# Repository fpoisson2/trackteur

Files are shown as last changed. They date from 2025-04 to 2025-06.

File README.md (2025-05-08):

# Suivi de véhicule DIY pour Traccar

Ce dépôt propose une solution complète de suivi de véhicule en temps réel, basée sur Arduino, GPS et GSM/GPRS, et compatible avec la plateforme Traccar (https://www.traccar.org/).

## Structure du dépôt
- `code/` : code source Arduino
- `pcb/` : fichiers de conception PCB sous KiCad
- `logo.png` : logo du projet

## Description
Le système récupère les données GPS, les enregistre sur une carte SD (formaté avec Petit FatFs) et les transmet via un module LTE ou GPRS à un serveur Traccar, permettant de suivre la position du véhicule sur une interface web.

Le projet est compatible avec les modules suivants :
 - SIM7000G (LTE-M / NB-IoT)
 - SIM7070G (LTE-M / NB-IoT)
 - A7670E (LTE Cat-1)

Le code détecte automatiquement le module connecté et ajuste les commandes AT, la gestion du GNSS et les protocoles réseau.

## Matériel requis
- Arduino (Pro Mini, Uno, etc.)
- Module LTE/GPRS : SIM7000G, SIM7070G ou A7670E
- Carte SD et lecteur de carte SD
- Antennes GPS et GSM
- Câbles de connexion
- Alimentation (5 V ou batterie LiPo)

## Installation et utilisation
1. Cloner le dépôt :
   ```
   git clone https://github.com/votre-utilisateur/projet-suivi-vehicule.git
   ```
2. Ouvrir le dossier `code/` dans l'IDE Arduino.
3. Configurer les paramètres dans `code.ino` (serveur Traccar, APN, broches, etc.).
4. Connecter le matériel :
   - Module LTE/GSM vers broches RX/TX (utilise SoftwareSerial)
   - Lecteur SD sur SPI (pins 10–13)
5. Insérer la carte SIM et la carte SD.
6. Alimenter le montage.
7. Lancer votre serveur Traccar et vérifier la réception des positions.

## Personnalisation
- Adapter les constantes (APN, intervalles d'envoi) dans `common.h`.
- Modifier les broches et configurations dans `code.ino` selon votre matériel.

## Contribution
Les contributions sont les bienvenues !  
Forkez le dépôt, créez une branche et ouvrez une pull request.

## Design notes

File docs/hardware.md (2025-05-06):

# Matériel

## Schéma électrique

Insérez ici le schéma du circuit et le PCB exporté.

## Liste des composants (BOM)

| Quantité | Référence | Description |
|---|---|---|
| 1 | Arduino | Nano ou Pro Mini |

(Compléter avec toutes les pièces.)

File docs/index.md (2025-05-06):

# Documentation du Trackteur Arduino

Bienvenue dans la documentation du projet Trackteur Arduino.

Ce site couvre :

- Présentation du projet
- Matériel
- Guide d'assemblage
- Logiciel (configuration & déploiement)
- Dépannage / FAQ
- Contribution

Utilisez le menu à gauche pour naviguer.

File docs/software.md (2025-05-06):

# Logiciel

## Prérequis

- Arduino IDE (>=1.8)
- Bibliothèques : TinyGPS++, SdFat, GSMStream (ou équivalent)

## Installation

```bash
arduino-cli compile --fqbn arduino:avr:nano code/code.ino
arduino-cli upload -p /dev/ttyUSB0 --fqbn arduino:avr:nano code/code.ino
```

## Configuration

- APN opérateur
- URL Traccar
- Config pins dans common.h

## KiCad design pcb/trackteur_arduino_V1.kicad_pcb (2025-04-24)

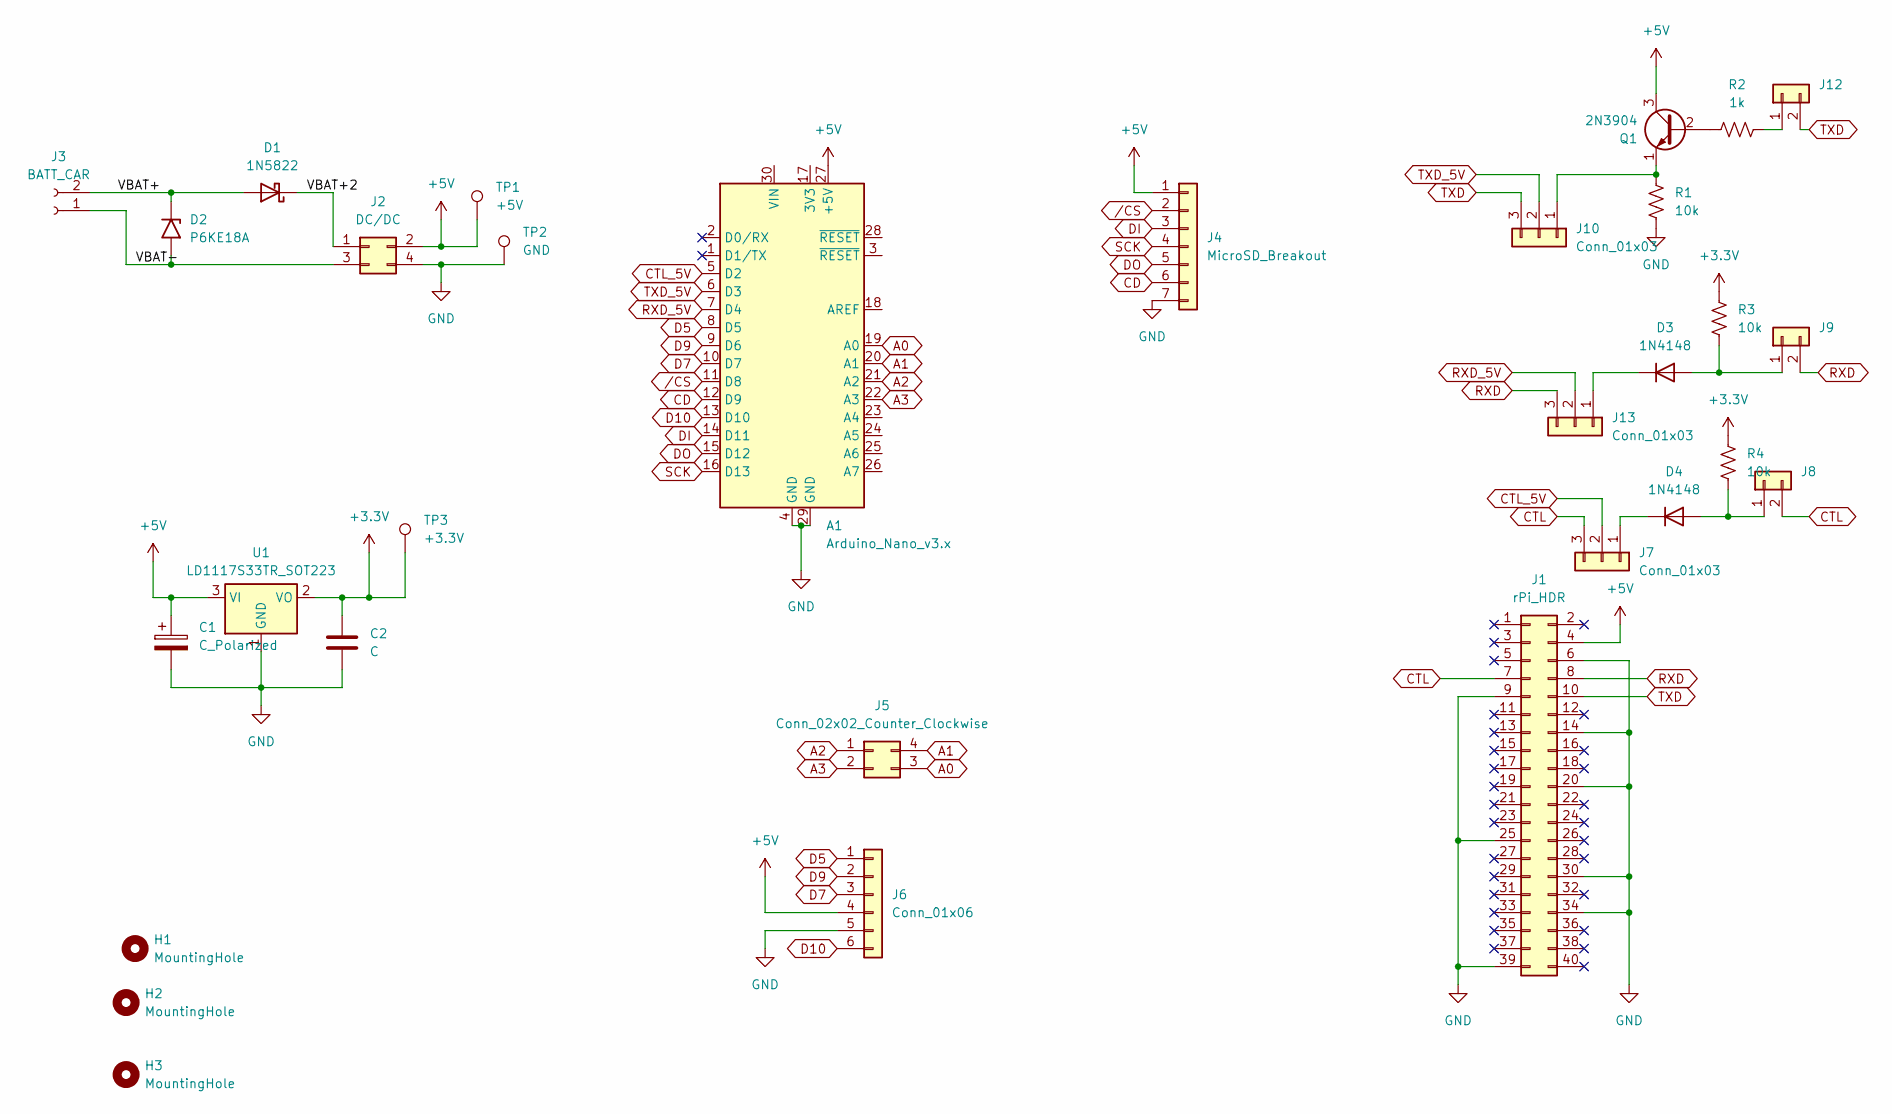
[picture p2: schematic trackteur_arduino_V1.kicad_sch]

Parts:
A1: Arduino_Nano_v3.x; Arduino_Nano
C1: C_Polarized; CP_Radial_D5.0mm_P2.50mm
C2: C; C_Disc_D5.0mm_W2.5mm_P5.00mm
D1: 1N5822; D_DO-201AD_P15.24mm_Horizontal
D2: P6KE18A; D_DO-15_P12.70mm_Horizontal
D3, D4: 1N4148; D_DO-35_SOD27_P7.62mm_Horizontal
H1, H2, H3: MountingHole; MountingHole_2.7mm_M2.5
J1: rPi_HDR; PinHeader_2x20_P2.54mm_Vertical
J2: DC/DC; LM2596_DC_DC_MODULE
J3: BATT_CAR; TE_282837-2
J4: MicroSD_Breakout; PinHeader_1x07_P2.54mm_Vertical
J5: Conn_02x02_Counter_Clockwise; PinHeader_2x02_P2.54mm_Vertical
J6: Conn_01x06; PinHeader_1x06_P2.54mm_Vertical
J7, J10, J13: Conn_01x03; PinHeader_1x03_P2.54mm_Vertical
J8, J9, J12: Conn_01x02; PinHeader_1x02_P2.54mm_Vertical
Q1: 2N3904; TO-92_Inline
R1, R3, R4: 10k; R_Axial_DIN0207_L6.3mm_D2.5mm_P10.16mm_Horizontal
R2: 1k; R_Axial_DIN0207_L6.3mm_D2.5mm_P10.16mm_Horizontal
TP1: +5V; PinHeader_1x01_P2.54mm_Vertical
TP2: GND; PinHeader_1x01_P2.54mm_Vertical
TP3: +3.3V; PinHeader_1x01_P2.54mm_Vertical
U1: LD1117S33TR_SOT223; TO-220-3_Vertical

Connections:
+3.3V: C2.1, R3.2, R4.2, TP3.1, U1.2 (VO)
+5V: A1.27 (+5V), C1.1, J1.4, J2.2, J4.1, J6.4, Q1.3 (C), TP1.1, U1.3 (VI)
/VBAT+: D1.2 (A), D2.1 (A1), J3.2
/VBAT+2: D1.1 (K), J2.1
/VBAT-: D2.2 (A2), J2.3, J3.1
A0: A1.19 (A0), J5.3
A1: A1.20 (A1), J5.4
A2: A1.21 (A2), J5.1
A3: A1.22 (A3), J5.2
CD: A1.12 (D9), J4.6
CTL: J1.7, J7.3, J8.2
CTL_5V: A1.5 (D2), J7.2
D5: A1.8 (D5), J6.1
D7: A1.10 (D7), J6.3
D9: A1.9 (D6), J6.2
D10: A1.13 (D10), J6.6
DI: A1.14 (D11), J4.3
DO: A1.15 (D12), J4.5
GND: A1.4 (GND), A1.29 (GND), C1.2, C2.2, J1.6, J1.9, J1.14, J1.20, J1.25, J1.30, J1.34, J1.39, J2.4, J4.7, J6.5, R1.1, TP2.1, U1.1 (GND)
unnamed: D3.2 (A), J9.1, R3.1
unnamed: D3.1 (K), J13.1
unnamed: D4.2 (A), J8.1, R4.1
unnamed: D4.1 (K), J7.1
unnamed: J10.1, Q1.1 (E), R1.2
unnamed: J12.1, R2.2
unnamed: Q1.2 (B), R2.1
RXD: J1.8, J9.2, J13.3
RXD_5V: A1.7 (D4), J13.2
SCK: A1.16 (D13), J4.4
TXD: J1.10, J10.3, J12.2
TXD_5V: A1.6 (D3), J10.2
/CS: A1.11 (D8), J4.2

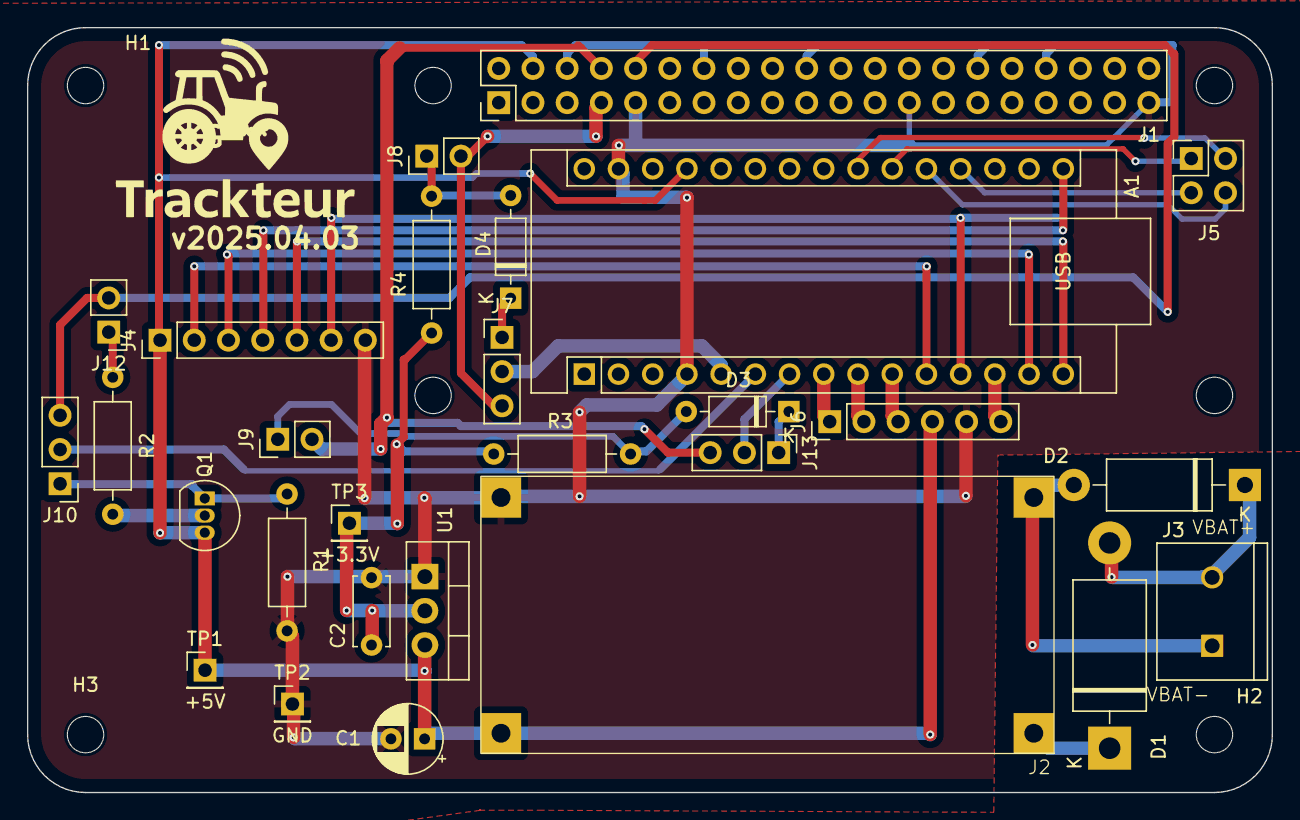
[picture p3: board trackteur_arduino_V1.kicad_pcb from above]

Board: 2 copper layers, 92.4 x 56.8 mm, 35 parts (0 on the bottom side), 32 nets.

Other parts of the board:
H2#2, H4, H5: MountingHole_2.7mm_M2.5
H3#2: MountingHole; MountingHole_2.7mm_M2.5

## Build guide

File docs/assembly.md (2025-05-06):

# Assemblage pas-à-pas

## Pré-requis

- Fer à souder
- Multimètre
- Tournevis

## Étapes

1. Soudure des résistances et condensateurs
2. Insertion des supports SIM et µSD
3. Montage du module GSM/GPS
4. Vérification des connexions
5. Montage dans le boîtier

Ajoutez des photos à chaque étape.

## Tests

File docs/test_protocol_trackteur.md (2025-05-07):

# Protocole de Validation Exhaustif — Projet **Trackteur**

**Version :** 1.0   **Révision du firmware testée :** `$(git rev-parse --short HEAD)`

*NB : ce protocole s’appuie sur l’implémentation exacte observée dans le dépôt (fichiers `code/*`). Les libellés, messages **Serial** et noms de fonctions cités proviennent du code source et permettent une traçabilité directe entre les tests et l’implémentation.*

---

## Table des matières
1. Objectifs et portée
2. Prérequis
   2.1 Matériel 2.2 Logiciel 2.3 Préparation du banc
3. Convention de nommage & journalisation
4. Plan de test détaillé (pas-à-pas)
   * 4.1 Initialisation « cold-boot »
   * 4.2 Pile réseau LTE & détection SIM
   * 4.3 GNSS : acquisition & parsing (`getGpsData`)
   * 4.4 SD : moteur Petit FatFs (`sdlog.cpp`)
   * 4.5 Flux Traccar (`sendGpsToTraccar`)
   * 4.6 Watch-dog & résilience (`serviceNetwork`, `resetGsmModule`)
   * 4.7 Tests de bordure & corruption (fichiers, buffers, wrap-around)
5. Critères de succès/échec
6. Collecte des preuves & archivage
7. Annexes

---

## 1. Objectifs et portée

Valider que **Trackteur** – matériel, firmware et logique back-end – fonctionne dans toutes les conditions prévues par le code (fichiers `code/*.cpp`).

• Fiabilité du boot, absence de sur-consommation (< 200 mA @ 5 V lors du pic d’initialisation observé dans `setup()`).  
• Bon déroulement de la séquence **`serviceNetwork()`** : `initialCommunication()` ► `step1…4` ► état `NetState::ONLINE`.  
• Performance des fonctions critiques : `getGpsData`, `openDataStack`, `tcpSend`, `logRealPositionToSd`, etc.  
• Robustesse face aux fautes : perte réseau, corruption secteur, overflow de buffers (**`RESPONSE_BUFFER_SIZE` = 128 octets**), redémarrage forcé (watch-dog).  
• Conformité du format de trame HTTP GET attendu par Traccar.

## 2. Prérequis

### 2.1 Matériel

| Réf | Qté | Détails |
|---|---|---|
| Carte Trackteur assemblée | 2 | Une avec **SIM7000G**, une avec **A7670E** (détection via `ATI`) |
| Alim de labo 5 V / 2 A | 1 | Lim courant ajustable |
| Batterie Li-ion 18650 2400 mAh | 1 | Test coupure secteur |
| Câble USB-TTL 115 200 bps mini | 1 | Console debug (pins RX0/TX0) |
| Antennes LTE & GNSS | 1+1 | Connecteurs U.FL ≈50 Ω |
| SIM M2M **data** | 1 | APN : *onomondo* (cf. `const char* APN`) |
| micro-SD 4 Go class 10 | 1 | Format FAT32, sector size 512 o |
| PC Windows/Linux | 1 | Ports USB, Python ≥ 3.8 |
| Multimètre + oscillo ≥ 50 MHz | - | Vér. VCC, bruit, toggles GPIO |
| Cage Faraday (boite métal) | - | Simuler perte réseau |

### 2.2 Logiciel

• Toolchain Arduino / PlatformIO (AVR-gcc 5+).  
• Terminal série : `minicom`, `PuTTY` ou équivalent **avec log cru**.  
• Python 3 + dépendances (`pyserial`, `pandas`) : scripts `tools/trackteur_harness.py` (fourni).  
• Serveur **Traccar** (v5+) local : accès au log `tracker-server.log`.  
• Optionnel : simulateur NMEA (plages de tests GNSS en intérieur).

### 2.3 Préparation du banc

1. Flasher la révision *release-candidate* (`git checkout <tag>`).  
2. Sauvegarder le SHA-1 dans la feuille de résultat.  
3. Vérifier soudures, polarités et **continuité D2** (GPIO `powerPin`).  
4. Insérer la micro-SD puis exécuter `initializeSD()` via un sketch simple : assure un montage OK avant campagne.  
5. Insérer la carte SIM, antennes GNSS & LTE (vérifier pas d’inversion).  
6. Relier la console série (115 200 bps). Activer *capture RAW*.

---

## 3. Convention de nommage & journalisation

• Un ID unique `T-<Domaine>-NNN` par cas (ex :`T-GSM-012`).  
• Tous les logs **Serial** doivent être conservés : `/logs/YYYY-MM-DD/<ID>.log`.  
• Scripts Python : chaque test écrit un CSV `/results/YYYY-MM-DD/<ID>.csv` avec **timestamp ISO8601**, `result`, `duration_ms`, et commentaires.  
• Photos/Vidéos : nom `IMG_<ID>_stepX.jpg`.

---

## 4. Plan de test détaillé

### Lecture des colonnes

* Pré-cond. = état et configuration à respecter avant déroulé.  
* Étapes = séquence manuelle/automatisée.  
* Attendu = critère de succès issu **des messages ou valeurs retournées**.  
* Timeout/itération = valeur max avant échec.

### 4.1 Cold-boot & Initialisation

| ID | Objectif | Pré-cond. | Étapes | Attendu / Timeout |
|----|---|---|---|---|
| T-BOOT-001 | Absence de sur-conso | Alim labo 5 V ; I_lim = 500 mA | Alimenter. | I_crête < 200 mA (lecture multimètre ‹ 5 s). |
| T-BOOT-002 | Bannière USB visible | UART ouvert 115 200 bps | Presse **RESET** MCU | Log « `--- Arduino Initialized ---` » < 1 s. |
| T-BOOT-003 | Setup terminé | | Observer console | « `=== SETUP TERMINÉ ===` » < 10 s. |
| T-BOOT-004 | Watchdog actif | Modifier `initializeWatchdog()` pour activer `wdt_enable(WDTO_8S)` et re-flasher | Laisser tourner 30 min | Aucun reset impromptu. |

### 4.2 Pile réseau & SIM

| ID | Objectif | Pré-cond. | Étapes | Attendu |
|----|---|---|---|---|
| T-GSM-010 | Détection modem | Démarrage normal | Vérifier log `>> Modem detected: ...` | Modèle correct (`SIM7000G` ou `A7670E`). |
| T-GSM-020 | `initialCommunication()` | | Surveiller log | Suite d’`OK` pour `ATE0`, `AT+CMEE=2` etc. |
| T-GSM-030 | APN configuré | | Chercher « `AT+CGDCONT=1,"IP","onomondo"` » | APN = constante `APN`. |
| T-GSM-040 | SIM Ready | | Confirmer `SIM Ready.` | Reçu < 15 s. |
| T-GSM-050 | Enregistré réseau | | `Registered.` dans log | ‹ 60 s sinon **E**. |
| T-GSM-060 | `openDataStack()` | | LOG « `✔ TCP connection successful` » ou `NETOPEN OK` | 3 tentatives max. |
| T-GSM-070 | Reconnexion OFFLINE→ONLINE | Forcer réseau OFF (boite Faraday 2 min) | Observer bascule `NetState::OFFLINE` puis reconnection | Reprise < RECONNECT_PERIOD (60 s). |

### 4.3 GNSS (`gps.cpp`)

| ID | Objectif | Étapes | Succès |
|----|---|---|---|
| T-GPS-100 | `getGpsData` valid – SIM7000 | Champ libre ciel dégagé | Temps fix (`run=1, fix=1`) < 45 s. |
| T-GPS-110 | `getGpsData` valid – A7670 | `AT+CGPSINFO` | Champs non-vides, TS parsé. |
| T-GPS-120 | Format timestamp | Inspecter buffer `gpsTimestampTraccar` | Format `YYYY-MM-DD%20hh:mm:ss`. |
| T-GPS-130 | Précision position | Comparer à coord. réf. (DGPS) | Δ < ±15 m. |
| T-GPS-140 | Robustesse buffer | Envoyer réponse +CGNSINF de 200 car. (script) | Pas d’overflow (taille définie 128). |

### 4.4 SD & journalisation sectorielle

| ID | Objectif | Étapes | Attendu |
|----|---|---|---|
| T-SD-200 | Montage FS | Power-up | « `Carte SD montée avec succès.` » |
| T-SD-210 | Écriture secteur | Forcer OFFLINE, laisser 5 positions | Secteur écrit, préfixe `!`, `sectorIndex` incrémente. |
| T-SD-220 | Marquage # envoyé | Reconnecter réseau puis appeler `resendLastLog()` | Secteur précédant passe `#`. |
| T-SD-230 | Corruption metadata | Éditer « GPS_LOG.CSV » : altérer signature | Au boot : log « `Signature invalide` » et `saveLogMetadata(1)`. |
| T-SD-240 | Overflow MAX_SECTORS | Simuler `sectorIndex=MAX_SECTORS+1` via debug | Index remis à 1. |

### 4.5 Transmission Traccar

| ID | Objectif | Étapes | Succès |
|----|---|---|---|
| T-NET-300 | Connexion TCP | `tcpOpen()` | « `✔ TCP connection successful` » sous 30 s. |
| T-NET-310 | Construction HTTP | Inspecter `httpReq` | Chaîne = `GET /?id=<DEVICE_ID>&lat=<lat>&lon=<lon>&timestamp=<ts>` + CRLFCRLF |
| T-NET-320 | `tcpSend` prompt | Vérifier réception char `>` | < 3 s. |
| T-NET-330 | `SEND OK` | Dans 10 s après payload | OK. |
| T-NET-340 | Fermeture propre | `tcpClose` → `CLOSE OK` ou `+CIPCLOSE:` | Fermé < 10 s. |
| T-NET-350 | Charge offline 200 trames | Forcer stock SD, rétablir réseau | 200 requêtes reçues dans **ordre ASC** (vér. log Traccar). |

### 4.6 Watch-dog & recovery

| ID | Objectif | Étapes | Succès |
|----|---|---|---|
| T-WDG-400 | `wdt_reset` appelé | Brancher oscillo sur pin 13, placer un `digitalWrite(13, !digitalRead(13));` dans `wdt_reset()` | Toggle périodique < 120 ms. |
| T-WDG-410 | Boucle bloquée | Injecter `while(1);` via serial debug (commande `DBG_LOCK`) | Reboot < 8 s. |
| T-WDG-420 | `resetGsmModule()` | Débrancher antenne LTE 5 min | Log « `*** Power-cycling GSM module ***` ». |
| T-WDG-430 | Compteur `consecutiveNetFails` | Simuler 5 échecs  réseau | Reset module puis compteur = 0. |

### 4.7 Bords, limites et injection d’erreurs

| ID | Scénario | Méthode | Attendu |
|----|---|---|---|
| T-ERR-500 | Buffer série plein | Script Python envoie 256 chars rapidement | Log `⚠️ overflow, flushing` puis fonctionnement normal. |
| T-ERR-510 | Wrap-around `sectorIndex` | Positionner `sectorIndex=MAX_SECTORS` +1 | Au log suivant, index=1, aucun crash. |
| T-ERR-520 | TCP refusé | Noter déconnexion serveur | `tcpOpen()` → échec ; firmware stocke data SD, reste ONLINE=false. |

---

## 5. Critères de succès / échec

• **Succès** : tous les IDs marqués « S » dans la feuille de résultats, aucune alarme critique (Serial « FATAL » ou « ERROR ») non résolue.  
• **Échec bloquant** : un seul KO dans les sections 4.1-4.5 impose correctif avant production.  
• **Échec non-bloquant** : cas de stress (4.7) peuvent ouvrir une **issue GitHub** sans stopper la série.

## 6. Collecte des preuves & archivage

1. Script `tools/collect_logs.py` : range `.log` et `.csv` automatiquement.  
2. Compression zip + checksum SHA-256.  
3. Push dans dépôt interne `validation/trackteur_tests_<date>.zip`.  
4. Rédiger ticket JIRA si KO.

## 7. Annexes

### A. Modèle de feuille de résultats

| ID | Date/Heure | Résultat (S/E) | Observateur | Notes |
|----|---|---|---|---|

### B. Commandes AT fréquentes (extrait)

```
ATI
AT+CPIN?
AT+CREG?
AT+CGATT?
AT+CGNSINF      # SIM7000
AT+CGPSINFO     # A7670
AT+CIPSTART="TCP","trackteur.ve2fpd.com",5055
AT+CIPSEND=<len>
```

### C. Points de mesure — PCB v1

| Repère | Désignation | Commentaire |
|---|---|---|
| TP1 | VCC_5V | 5 V régulateur LM2596 |
| TP2 | V_BAT | Li-ion après protection | 
| TP3 | D2 (PWRKEY) | Doit commuter 0 → 1 pour ON module |

---

**Fin de document – Protocole de test Trackteur**

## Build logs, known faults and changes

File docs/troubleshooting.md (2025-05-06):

# Dépannage / FAQ

## Aucune réponse GPS
- Vérifier antenne et positionnement

## Échec de connexion GSM
- Vérifier APN et couverture réseau

## Carte SD non détectée
- Contrôler les pistes et alimentation 3.3V

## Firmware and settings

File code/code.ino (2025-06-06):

/* =======================================================================
 * Projet      : Traceur GPS LTE avec enregistrement SD et envoi Traccar
 * Fichier     : main.ino
 * Description : Initialise le module GSM/GNSS SIM7000G, lit les coordonnées GPS,
 *               envoie les données à un serveur Traccar via TCP et journalise
 *               localement sur carte SD en cas d'échec réseau. Implémente une
 *               logique de reprise et de nettoyage des logs non transmis.
 * Auteur      : Francis Poisson-Gagnon
 * Date        : 2025-05-05
 * Cible       : Arduino Nano (ATmega328P)
 * Dépôt Git   : https://github.com/fpoisson2/trackteur
 * 
 * Dépendances :    if (getGpsData(currentLat, currentLon, gpsTimestampTraccar)) {
 *   - common.h         : Définitions globales, watchdog, constantes
 *   - sdlog.h/.cpp     : Gestion de la carte SD avec Petit FatFs
 *   - gsm.h/.cpp       : Communication série AT avec le module LTE
 *   - gps.h/.cpp       : Extraction et formatage des données GNSS
 *   - traccar.h/.cpp   : Format et envoi vers Traccar via TCP
 * ======================================================================= */

#include "config.h"
#include "logging.h"
#include "common.h"
#include "sdlog.h"
#include "gsm.h"
#include "gps.h"
#include "traccar.h"



void setup() {
  initializeWatchdog();
  initializeSerial();

  initializeSD();
  sectorIndex = loadLogMetadata();
  DBG(F("Resuming at sector ")); DBGLN(sectorIndex);

  initializeModulePower(); // met sous tension le module LTE

  netState = NetState::BOOTING;
  lastSendTime = millis();
  lastGpsPoll = millis();
  initialAT();
  serviceNetwork();
  step4EnableGNSS();
  INFOLN(F("Setup terminé"));
}

void loop() {
  wdt_reset();

  serviceNetwork();

  // Lecture GPS périodique
  if (millis() - lastGpsPoll >= GPS_POLL_INTERVAL) {
if (getGpsData(currentLat, currentLon, gpsTimestampTraccar)) {
  DBG(F("GPS OK: Lat=")); DBG2(currentLat, 6);
  DBG(F(" Lon="));        DBG2(currentLon, 6);
  DBG(F(" Time="));       DBGLN(gpsTimestampTraccar);
  consecutiveGpsFails = 0;
  if (gsmModel == GSM_SIM7070) {
    disableGNSS();
  }

  Serial.println(toStr(netState));

  // Mise à jour de l'état du réseau (connexion, reconnexion si besoin)
  if (netState == NetState::ONLINE) {
    memset(responseBuffer, 0, sizeof(responseBuffer));
    responseBufferPos = 0;

    bool ok = sendGpsToTraccar(TRACCAR_HOST, TRACCAR_PORT, DEVICE_ID, currentLat, currentLon, gpsTimestampTraccar);
    if (ok) {
      DBGLN(F(">>> Send OK."));
      consecutiveNetFails = 0;

      // vidange des anciennes données seulement
      resendLastLog();
    } else {
      INFO(F("Network fail #")); 
      INFOLN(++consecutiveNetFails);
      DBGLN(F(">>> Send FAIL."));
      
      // Log uniquement si l'envoi a échoué
      logRealPositionToSd(currentLat, currentLon, gpsTimestampTraccar);

      if (consecutiveNetFails >= NET_FAIL_THRESHOLD) {
        DBGLN(F(">>> Trop d'échecs réseau, on redémarre le module GSM."));
        netState = NetState::OFFLINE;
        lastReconnectAttempt = millis();
        consecutiveNetFails = 0;
      }
    }

  } else {
    DBGLN(F("Pas de réseau, stockage uniquement."));
    logRealPositionToSd(currentLat, currentLon, gpsTimestampTraccar);
  }
  step4EnableGNSS();
}
 else {
      consecutiveGpsFails++;
      DBGLN(F(">>> Aucun fix GPS."));
      if(consecutiveGpsFails > GPS_FAIL_THRESHOLD) {
        PowerOff();
        while(true);
      }
    }

    lastGpsPoll = millis();
  }

  delay(100);
}

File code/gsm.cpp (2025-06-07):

/* =======================================================================
 * Projet      : Traceur GPS LTE avec SD et Traccar
 * Fichier     : gsm.cpp
 * Description : Gère la communication série avec le module SIM7000G.
 *               Fournit les fonctions de configuration réseau, gestion
 *               GNSS, PDP context, et commandes AT avec accusé de réception.
 *               Comprend également la logique de redémarrage du module.
 *
 * Auteur      : Francis Poisson-Gagnon
 * Dépôt Git   : https://github.com/fpoisson2/trackteur
 * Matériel    : SIM7000G + Arduino Nano (ATmega328P)
 * ======================================================================= */

#include "config.h"
#include "logging.h"
#include "common.h"
#include "gsm.h"

// --- PDP / pile data -------------------------------------------------
bool openDataStack()
{
  if (gsmModel == GSM_A7670) {
    // A7670E : APN + NETOPEN
    clearSerialBuffer();
    snprintf_P(responseBuffer, sizeof(responseBuffer), PSTR("AT+CGDCONT=1,\"IP\",\"%s\",\"0.0.0.0\",0,0"), APN);
    if (!executeSimpleCommand(responseBuffer, "OK", 1000, 3)) return false;


    // NETOPEN avec trois tentatives
     for (uint8_t i = 0; i < 3; i++) {
      moduleSerial.println(F("AT+NETOPEN"));
      readSerialResponse(10000UL);
    
      // Si pas de "+NETOPEN:" dans la première réponse, on attend la suite
      if (!strstr(responseBuffer, "+NETOPEN:")) {
        readSerialResponse(10000UL);  // attend la suite potentielle
      }
    
      if (strstr(responseBuffer, "+NETOPEN: 0") || strstr(responseBuffer, "already opened")) {
        executeSimpleCommand("AT+CIPRXGET=1", "OK", 1000, 2);
        return true;
      }
      delay(500);
    }
    return false;
  }
  if (gsmModel == GSM_SIM7070) {
    snprintf_P(responseBuffer, sizeof(responseBuffer), PSTR("AT+CGDCONT=1,\"IP\",\"%s\""), APN);
    if (!executeSimpleCommand(responseBuffer, "OK", 500, 3)) return false;
    return executeSimpleCommand("AT+CNACT=0,1", "ACTIVE", 8000, 2);
  }
  if (gsmModel == GSM_SIM7000) {
    bool ok = true;
  
    ok &= executeSimpleCommand("AT+CIPSHUT", "SHUT OK", 3000, 2);
    ok &= executeSimpleCommand("AT+CIPMUX=0", "OK", 1000, 2);
    ok &= executeSimpleCommand("AT+CIPRXGET=1", "OK", 1000, 2);
  
    snprintf_P(responseBuffer, sizeof(responseBuffer), PSTR("AT+CSTT=\"%s\",\"\",\"\""), APN);
    ok &= executeSimpleCommand(responseBuffer, "OK", 1000, 2);
  
    ok &= executeSimpleCommand("AT+CIICR", "OK", 5000, 2);
    ok &= executeSimpleCommand("AT+CIFSR", ".", 3000, 2);  // On vérifie simplement qu’une IP est renvoyée
  
    return ok;
  }

}

bool closeDataStack()
{
  if (gsmModel == GSM_A7670) {
    return executeSimpleCommand("AT+NETCLOSE", "+NETCLOSE:", 3000, 2);
  }
  else if (gsmModel == GSM_SIM7070) {
    // On essaie de fermer la socket (si elle existe)
    executeSimpleCommand("AT+CACLOSE=0", "OK", 2000, 1);  // Ignorer l'échec
    // On tente de désactiver la session PDP même si elle n’est pas active
    //executeSimpleCommand("AT+CNACT=0,0", "OK", 3000, 1);   // Idem : ignorer erreur
    delay(500); 
    return true;  // On considère que c'est "fermé" même si aucune session n'était active
  }
  else {
    return executeSimpleCommand("AT+CIPSHUT", "SHUT OK", 3000, 2);
  }
}


bool tcpOpen(const char* host, uint16_t port)
{
  clearSerialBuffer();

  if (gsmModel == GSM_A7670) {
    snprintf_P(responseBuffer, sizeof(responseBuffer), PSTR("AT+CIPOPEN=0,\"TCP\",\"%s\",%u"), host, port);

    moduleSerial.write((const uint8_t*)responseBuffer, strlen(responseBuffer));
    moduleSerial.write('\r');

    delay(500); // stabilité
    if (waitForSerialResponsePattern("+CIPOPEN: 0,0", 30000UL)) {
      INFOLN(F("✔ TCP connection successful (A7670)"));
      return true;
    }
    return false;

   } else if (gsmModel == GSM_SIM7000) {
    snprintf_P(responseBuffer, sizeof(responseBuffer), PSTR("AT+CIPSTART=\"TCP\",\"%s\",%u"), host, port);
    moduleSerial.write((const uint8_t*)responseBuffer, strlen(responseBuffer));
    moduleSerial.write('\r');

    delay(500);
    readSerialResponse(2000UL);
    
    // Check for three possible success patterns:
    // 1. "CONNECT OK" with space (ideal case)
    // 2. "OKCONNECT OK" (as seen in your log)
    // 3. "OK" followed by "CONNECT OK" in a separate response
    if (strstr(responseBuffer, "CONNECT OK") || 
        strstr(responseBuffer, "OKCONNECT OK") ||
        strstr(responseBuffer, "OK")) {
      
      // If we just have OK, wait for the CONNECT OK to follow
      if (!strstr(responseBuffer, "CONNECT") && strstr(responseBuffer, "OK")) {
        if (!waitForSerialResponsePattern("CONNECT OK", 10000UL)) {
          return false;
        }
      }
      return true;
  }
   }
  else if (gsmModel == GSM_SIM7070) {
  
    // 3) Vider le buffer
    clearSerialBuffer();
  
    // 4) Construire et envoyer CAOPEN
    snprintf_P(responseBuffer, sizeof(responseBuffer),
               PSTR("AT+CAOPEN=0,0,\"TCP\",\"%s\",%u"),
               host, port);
  
    if (!executeSimpleCommand(responseBuffer, "+CAOPEN: 0,0", 15000UL, 1)) {
      return false;
    }

    executeSimpleCommand("AT+CASTATE?", "", 1000UL, 1);
  
    INFOLN(F("TCP connection successful"));
    return true;
  }
  return false;
}


bool waitForSerialResponsePattern(const char* pattern,
                                  unsigned long totalTimeout = 30000UL,
                                  unsigned long pollInterval = 200UL)
{
  unsigned long start = millis();
  while (millis() - start < totalTimeout) {
    readSerialResponse(pollInterval);
    if (strstr(responseBuffer, pattern)) return true;
    if (strstr(responseBuffer, "ERROR") || strstr(responseBuffer, "+CME ERROR")) {
      DBGLN(F("❌ Error detected while waiting for pattern."));
      return false;
    }
  }
  DBGLN(F("❌ Timeout waiting for expected response."));
  return false;
}
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

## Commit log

2025-03-31 Restructure des dossiers
    [lora_test_results_20250318_152836.csv, lora_test_results_20250318_153746.csv, lora_test_results_20250318_154248.csv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]
2025-03-31 ajout de dossiers
2025-04-02 arduino LTE-M first tests
2025-04-03 Ajout PCB
    [trackteur_arduino_V1.dsn, trackteur_arduino_V1.kicad_pcb, trackteur_arduino_V1.kicad_sch]
2025-04-03 update PCB
    [trackteur_arduino_V1.kicad_pcb, trackteur_arduino_V1.kicad_sch]
2025-04-03 Fichiers de fabrication
    [trackteur_arduino_V1-B_Cu.gbr, trackteur_arduino_V1-B_Mask.gbr, trackteur_arduino_V1-B_Paste.gbr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]
2025-04-03 add logo
    [lora_test_results_20250318_152836.csv, lora_test_results_20250318_153746.csv, lora_test_results_20250318_154248.csv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]
2025-04-24 LTE send dummy gps working and new pcb
    [trackteur_arduino_V1-B_Cu.gbr, trackteur_arduino_V1-B_Mask.gbr, trackteur_arduino_V1-B_Paste.gbr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]
2025-04-24 update PCB gerbers
    [trackteur_arduino_V1-B_Cu.gbr, trackteur_arduino_V1-B_Mask.gbr, trackteur_arduino_V1-B_Paste.gbr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]
2025-04-29 new gerbers
2025-05-05 add detection of gsm module and conneciton logic in loop for connection failover management
    [gsm.cpp]
2025-05-08 Révision séquence power-up
2025-05-11 déplacement des paramètes importants
2025-05-13 seems to have a bug with sim7000g
    [code.ino, gsm.cpp]
2025-06-07 ca semble bon, je cherche les bogues...
